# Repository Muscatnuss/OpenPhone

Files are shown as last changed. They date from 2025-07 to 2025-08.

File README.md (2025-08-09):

# Open Phone

# ToDo
- [ ] Accessories
	- [ ] Flashlight
- [ ] Human Interface
	- [ ] Vibration
	- [ ] Speaker
	- [ ] Fingerprint Sensor
- [ ] Connectivity
	- [x] Data - USB-C
		- [x] (SBUS Data)
	- [ ] (LORA communication)
		- meshtastic
	- [x] Cellular
- [ ] Sensors
	- [x] IMU
	- [x] Magnetometer
	- [ ] Fingerprint
- [ ] Video
	- [ ] Display
	- [ ] Camera
	- [ ] HDMI
- [ ] Audio
	- [ ] cellular audio $\to$ USB
	- [ ] CM5 audio IO
- [ ] Power
	- [ ] Load Switch 
		- [x] Modem
		- [ ] Camera
		- [ ] Mic
	- [x] USB-C Power delivery
	- [x] Power usage monitoring
		- [x] Current Monitor
		- [x] Voltage Monitor
# Hardware
- Back of PCB should face the screen
	- only very flat components on back
- PCB cutout for battery
    - Battery and PCB are on the same height to save space 

## Thermal management
- all significant heat producers face back
- Battery and screen keep a distance to hot spots

## Controller
Raspberry pi compute Module
https://www.raspberrypi.com/documentation/computers/compute-module.html#compute-module-5
https://datasheets.raspberrypi.com/cm5/cm5-datasheet.pdf
$\to$ 5V supply
$\to$ [Board connector](https://www.mouser.de/ProductDetail/Amphenol-FCI/10164227-1001A1RLF?qs=MyNHzdoqoQIc%2Fqhi8q%2FTOw%3D%3D)
Normalbetrieb unter Last $\to$ ~500mA

## Speicher
### SD Karte
- over SPI

## Screen
IPhone Xr 460ppi  ~6 Zoll

| | size  | maße | resolution  | price | Flex | Händler |
| --- | ----- | --- | --- | ----- | ---- | --- |
| [FLEX](https://www.alibaba.com/product-detail/Super-Thin-6-67-inch-1080_1601047701892.html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) | 6,67" | 165,16mm x 71,532mm x 0,33mm | 1080 x 2160 | 95€ | ja | Alibaba |
| [6" Flex](https://www.alibaba.com/product-detail/360-Degree-Bendable-6-Inch-Flexible_1600485553315.html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) | 6" | 68.04 x 136,08mm | 1080 x 2160 | 95€ | ja | Alibaba |

## Connectivity

- WLan $\to$ schon da
- Bluetooth $\to$  schon da
- micro HDMI $\to$ just add connector
- Ethernet?
- Phone network
- NFC
- USB-C
	- device mode
	- host mode
		- USB-Sticks und so
- Headphone-jack

### 3G 4G 5G

| Link | Price | | | Manual |
| --- | ----- | --- | --- | --- |
| https://mc-technologies.com/produkt/162368/ | 70€ | | | |
| SIM7600G-H | ~40€  | mit GPS | Dev-Board müsste man nachbauen, sollte aber nicht so wild sein | https://fcc.report/FCC-ID/2AJYU-8PYA007/4857209.pdf |
| | | | | |

[NAU8810](https://octopart.com/de/datasheet/nau8810yg-nuvoton-29622521 ) $\to$ Audio Codec
[Microphone](https://octopart.com/de/ics-40618-invensense-71346755)

## Powersupply
$\to$ 5V Akku Ladeelektronik
[load switch](https://www.ti.com/lit/ds/symlink/tps22917.pdf?ts=1749349462384)

### Battery Controller
Charge and boost controller, Power Path Management
availlable JLC
[BQ25895](https://www.ti.com/lit/ds/symlink/bq25895.pdf) ~3€

### Battery

| Kapazität | Maße | Preis | Händler |
| --- | --- | ----- | --- |
| [5000mAh](https://www.alibaba.com/product-detail/Lithium-Polymer-ultra-Thin-Lipo-3_1868172466.html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) | 6 x 50 x 82 | 3,80€ | Alibaba |
| [5500mAh](https://www.alibaba.com/product-detail/3-7-V-407595-5500mah-Factory_62168748778.html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) | 4 x 75 x 95mm  | 6,39€ | Alibaba |
| [10000mAh](https://www.alibaba.com/product-detail/8065113-3-7V-Lipo-Battery-10000mah_62109571526.html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) | 8 x 65 x 113mm | 8,50€ | Alibaba |

## Sensors

- [[Inertial Measurement Unit|IMU]]
- 3D [[Magnetometer]]
- Fingerprint sensor
	- https://biometrics.mainguet.org/types/fingerprint/product/FPC/FPC_1020_flyer.pdf
		- SPI
- Camera

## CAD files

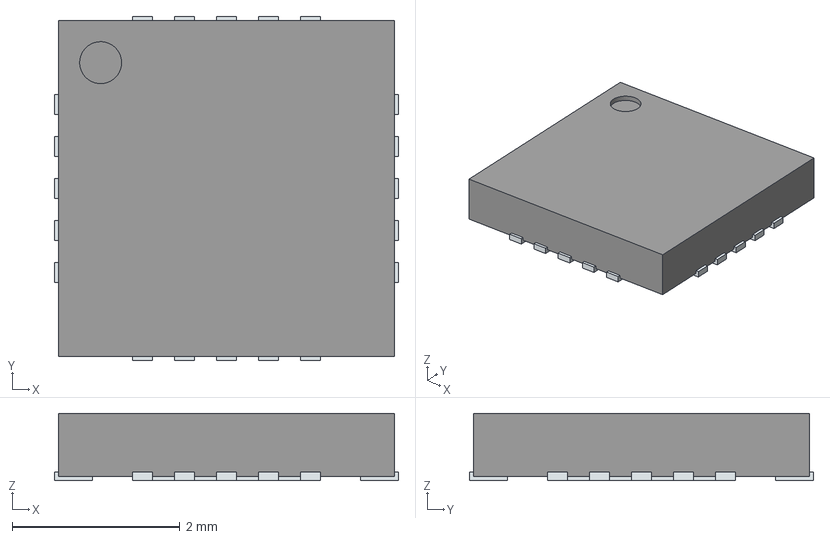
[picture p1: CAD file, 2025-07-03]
resources/LIB_NAU8810YG/NAU8810YG/3D/NAU8810YG.stp
4.10 x 4.10 x 0.8 mm
ThermalPin
PinsArrayLR
PinsArrayTB

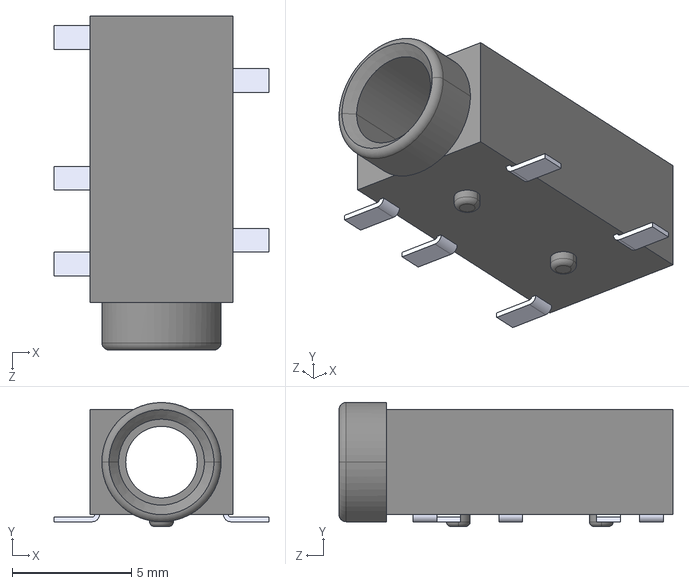
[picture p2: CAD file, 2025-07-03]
resources/10038075_A1PLF/10038075-A1PLF.step
9.00 x 5.20 x 14.0 mm

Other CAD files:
cad/SIM7600G-H.ipt
cad/mechanical/battery.ipt
cad/mechanical/battery_5000.ipt

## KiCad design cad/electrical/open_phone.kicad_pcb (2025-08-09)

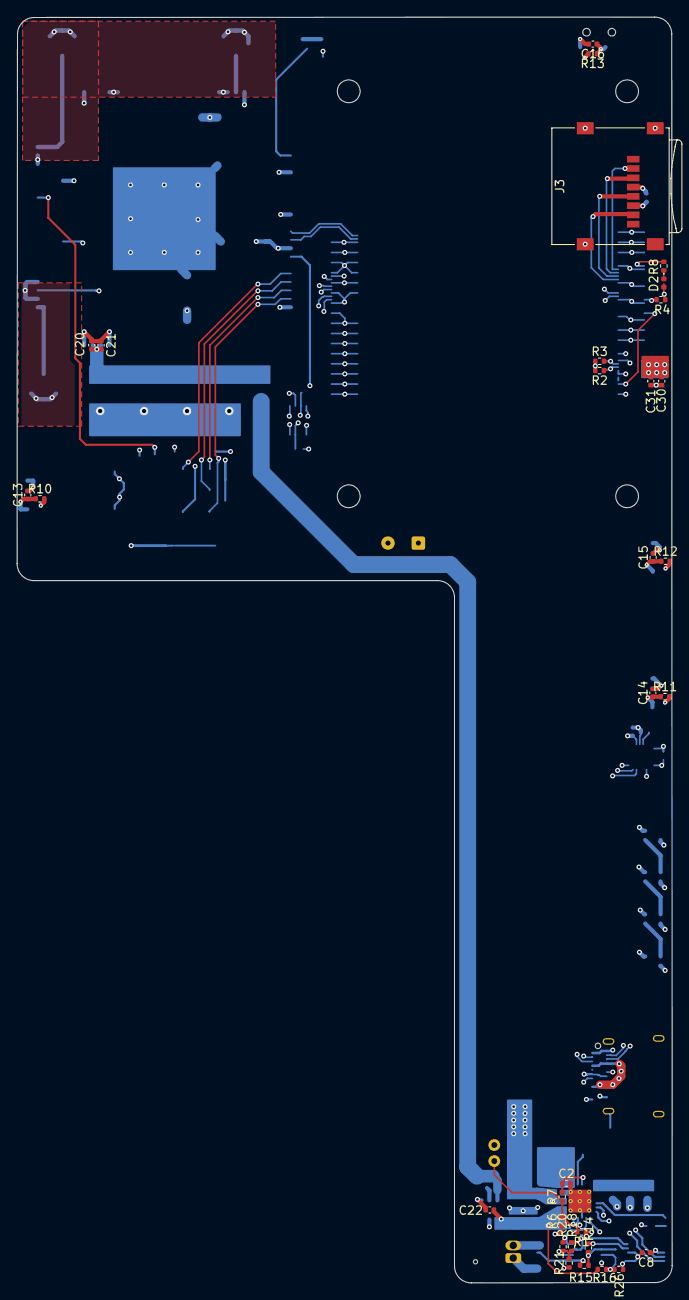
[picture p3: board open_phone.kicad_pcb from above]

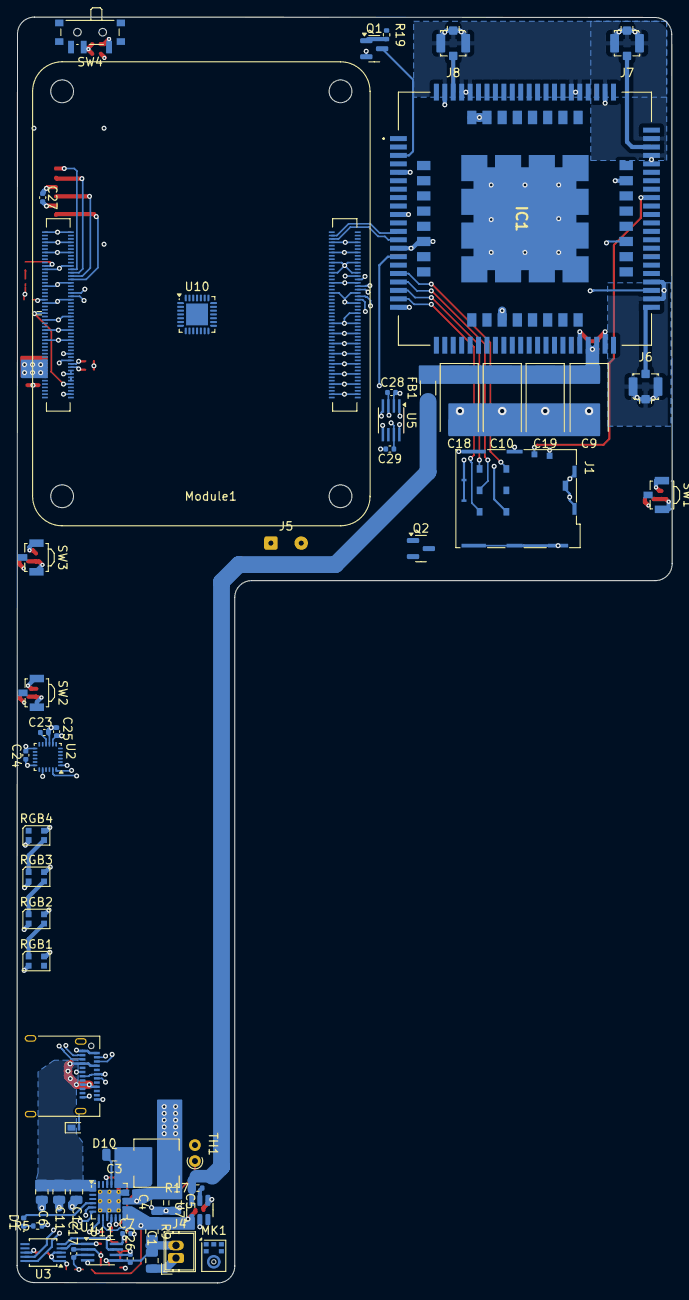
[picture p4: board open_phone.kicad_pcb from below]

Board: 6 copper layers, 77.6 x 150.0 mm, 87 parts (56 on the bottom side), 70 nets.

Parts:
C1, C3, C4, C5, C6, C11, C12: C; C_0805_2012Metric
C2, C7, C8, C13, C14, C15, C16, C17, C26, C27, C28, C29: C; C_0402_1005Metric
C9, C10, C18, C19: 100µF; CP_EIA-7343-31_Kemet-D
C20, C21, C22, C23, C24, C25, C30, C31: 100nF; C_0402_1005Metric
D1, D2: LED; LED_0402_1005Metric
D10: 12V; Nexperia_DSN1608-2_1.6x0.8mm
FB1: FerriteBead; L_1206_3216Metric
IC1: SIM7600G-H; SIM7600GH
J1: JAE_SIM_Card_SF72S006
J2: USB_C_Receptacle; USB_C_Receptacle_Amphenol_12401610E4-2A
J3: Micro_SD_Card; microSD_HC_Wuerth_693072010801
J4: Battery; Wuerth_WR-WTB_64800211622_1x02_P1.50mm_Vertical
J5: VIB; SolderWire-0.1sqmm_1x02_P3.6mm_D0.4mm_OD1mm
J6, J7, J8: conn_coax; U.FL_Molex_MCRF_73412-0110_Vertical
L1: L; L_Changjiang_FXL0518
MK1: ICS-43434; InvenSense_ICS-43434-6_3.5x2.65mm
Module1: ComputeModule5-CM5; Raspberry-Pi-5-Compute-Module
Q1, Q2: BC848; SOT-23
R1, R2, R3, R4, R5, R6, R7, R8, R10, R11, R12, R13, R14, R15, R16, R17, R18, R19, R20, R21, R26: R; R_0402_1005Metric
R9: R; R_0805_2012Metric
RGB1, RGB2, RGB3, RGB4: WS2812B-2020; LED_WS2812B-2020_PLCC4_2.0x2.0mm
SW1, SW2, SW3: SW_Push; SW_SPST_B3U-3100P
SW4: SW_SPST; SW_SPDT_PCM12
TH1: Thermistor_NTC; R_Axial_DIN0204_L3.6mm_D1.6mm_P1.90mm_Vertical
U1: BQ25895RTW; Texas_RTW_WQFN-24-1EP_4x4mm_P0.5mm_EP2.7x2.7mm_ThermalVias
U2: MPU-9250; InvenSense_QFN-24_3x3mm_P0.4mm
U3: ADS1013IDGS; TSSOP-10_3x3mm_P0.5mm
U5: TXS0102DCT; SSOP-8_2.95x2.8mm_P0.65mm
U7: TPS22917DBV; SOT-23-6
U10: ES8388; QFN-28-1EP_4x4mm_P0.45mm_EP2.6x2.6mm
U11: OPA2197xDGK; SSOP-8_2.95x2.8mm_P0.65mm

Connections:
+1V8: Module1.88 (+1.8v_(Output)), Module1.90 (+1.8v_(Output))
+1V8_CELL: C29.1, IC1.15 (VDD_1V8), U5.7 (VCCB)
+3.3V: C24.1, C25.1, C27.1, C28.2, D2.2 (A), J3.4 (VDD), J5.1, Module1.78 (GPIO_VREF(1.8v/3.3v_Input)), Module1.84 (+3.3v_(Output)), Module1.86 (+3.3v_(Output)), R2.2, R3.2, R4.2, RGB1.4 (VDD), RGB2.4 (VDD), RGB3.4 (VDD), RGB4.4 (VDD), U2.8 (VDDIO), U2.13 (VDD), U5.3 (VCCA)
+3V3: R10.2, R11.2, R12.2, R13.2, U2.1 (RESV_VDDIO)
+5V: C4.1, C5.1, C7.1, C8.1, C30.1, C31.1, L1.2, Module1.77 (+5v_(Input)), Module1.79 (+5v_(Input)), Module1.81 (+5v_(Input)), Module1.83 (+5v_(Input)), Module1.85 (+5v_(Input)), Module1.87 (+5v_(Input)), R5.1, R20.2, U1.15 (SYS), U1.16 (SYS), U3.8 (VDD), U11.8 (V+)
/cellular/MODEM_DBG_RX: IC1.106 (DBG_RXD), U5.8 (B1)
/cellular/MODEM_DBG_TX: IC1.42 (DBG_TXD), U5.1 (B2)
/cellular/MODEM_POWER: FB1.1, R17.1, U7.6 (VOUT)
/cellular/SW_MODEM: Module1.39 (GPIO8), U7.3 (ON)
/cellular/USB2_N: IC1.12 (USB_DN), Module1.103 (USB2_N)
/cellular/USB2_P: IC1.13 (USB_DP), Module1.105 (USB2_P)
/connectors/CC1: J2.A5 (CC1), Module1.94 (CC1)
/connectors/CC2: J2.B5 (CC2), Module1.96 (CC2)
/connectors/USB3-0-DN: J2.A7 (D-), J2.B7 (D-), Module1.134 (USB3-0-D_P)
/connectors/USB3-0-DP: J2.A6 (D+), J2.B6 (D+), Module1.136 (USB3-0-D_N)
/connectors/USB3-0-RX_N: J2.B10 (RX1-), Module1.130 (USB3-0-RX_P)
/connectors/USB3-0-RX_P: J2.B11 (RX1+), Module1.128 (USB3-0-RX_N)
/connectors/USB3-0-TX_N: J2.A3 (TX1-), Module1.142 (USB3-0-TX_P)
/connectors/USB3-0-TX_P: J2.A2 (TX1+), Module1.140 (USB3-0-TX_N)
/controller/CS: J3.2 (DAT3/CD), Module1.24 (GPIO26)
/controller/GPIO25: Module1.41 (GPIO25), R4.1, U1.7 (INT)
/controller/MISO: J3.3 (CMD), Module1.26 (GPIO19)
/controller/MOSI: J3.7 (DAT0), Module1.30 (GPIO6)
/controller/SCL0: Module1.80 (SCL0), R3.1, U1.5 (SCL), U2.23 (SCL/SCLK), U3.10 (SCL)
/controller/SCLK: J3.5 (CLK), Module1.28 (GPIO13)
/controller/SDA0: Module1.82 (SDA0), R2.1, U1.6 (SDA), U2.24 (SDA/MOSI), U3.9 (SDA)
/controller/UART0_RX: Module1.40 (GPIO9), U5.5 (A1)
/controller/UART0_TX: Module1.38 (GPIO11), U5.4 (A2)
BTTN_VOL_+: C14.1, R11.1, SW2.2
BTTN_VOL_-: C15.1, R12.1, SW3.2
BTTN_unlock: C13.1, Module1.49 (GPIO18), Module1.92 (PWR_BUT), R10.1, SW1.2
GND: C1.2, C2.2, C4.2, C5.2, C6.1, C7.2, C8.2, C9.2, C10.2, C11.1, C12.1, C13.2, C14.2, C15.2, C16.2, C18.2, C19.2, C20.2, C21.2, C23.2, C24.2, C25.2, C27.2, C28.1, C29.2, C30.2, C31.2, D10.2 (A), IC1.1 (GND_1), IC1.2 (GND_2), IC1.5 (GND_3), IC1.10 (GND_4), IC1.14 (GND_5), IC1.37 (GND_6), IC1.40 (GND_7), IC1.41 (GND_8), IC1.43 (GND_9), IC1.57 (GND_10), IC1.58 (GND_11), IC1.60 (GND_12), IC1.61 (GND_13), IC1.64 (GND_14), IC1.65 (GND_15), IC1.77 (GND_16), IC1.78 (GND_17), IC1.80 (GND_18), IC1.81 (GND_19), IC1.93 (GND_20), IC1.98 (GND_21), IC1.110 (GND_22), IC1.118 (GND_23), IC1.119 (GPIO_19), IC1.120 (GND_24), IC1.121 (GND_25), IC1.122 (GND_26), IC1.123 (GND_27), IC1.124 (GND_28), IC1.125 (GND_29), IC1.126 (GND_30), IC1.127 (GND_31), IC1.128 (GND_32), IC1.129 (GND_33), IC1.130 (GND_34), IC1.131 (GND_35), IC1.132 (GND_36), IC1.133 (GND_37), IC1.134 (GND_38), IC1.135 (GND_39), J1.C5 (GND), J1.DSW, J1.SH, J2.A1 (GND), J2.A12 (GND), J2.B1 (GND), J2.B12 (GND), J2.S1 (SHIELD), J3.6 (VSS), J3.9 (SHIELD), J4.1, J6.2 (Ext), J7.2 (Ext), J8.2 (Ext), Module1.1 (GND), Module1.2 (GND), Module1.7 (GND), Module1.8 (GND), Module1.13 (GND), Module1.14 (GND), Module1.22 (GND), Module1.23 (GND), Module1.32 (GND), Module1.33 (GND), Module1.42 (GND), Module1.43 (GND), Module1.52 (GND), Module1.53 (GND), Module1.59 (GND), Module1.60 (GND), Module1.65 (GND), Module1.66 (GND), Module1.74 (GND), Module1.98 (GND), Module1.107 (GND), Module1.108 (GND), Module1.113 (GND), Module1.114 (GND), Module1.119 (GND), Module1.120 (GND), Module1.125 (GND), Module1.126 (GND), Module1.131 (GND), Module1.132 (GND), Module1.137 (GND), Module1.138 (GND), Module1.144 (GND), Module1.150 (GND), Module1.155 (GND), Module1.156 (GND), Module1.161 (GND), Module1.162 (GND), Module1.167 (GND), Module1.168 (GND), Module1.173 (GND), Module1.174 (GND), Module1.179 (GND), Module1.180 (GND), Module1.185 (GND), Module1.186 (GND), Module1.191 (GND), Module1.192 (GND), Module1.197 (GND), Module1.198 (GND), Q1.2 (E), Q2.2 (E), R1.1, R6.1, R21.1, R26.2, RGB1.2 (VSS), RGB2.2 (VSS), RGB3.2 (VSS), RGB4.2 (VSS), SW1.1, SW2.1, SW3.1, SW4.1 (A), TH1.2, U1.9 (~CE), U1.17 (PGND), U1.18 (PGND), U1.25 (PGND), U2.9 (AD0/MISO), U2.18 (GND), U2.20 (RESV_GND), U3.1 (ADDR), U3.3 (GND), U5.2 (GND), U7.2 (GND), U11.4 (V-)
LED_nACT: Module1.21 (LED_nACT), R8.1
unnamed: C3.1, L1.1, U1.19 (SW), U1.20 (SW)
unnamed: D1.2 (A), U1.4 (STAT)
unnamed: D1.1 (K), R5.2
unnamed: D2.1 (K), R8.2
unnamed: IC1.59 (AUX_ANT), J7.1 (In)
unnamed: IC1.79 (GNSS_ANT), J8.1 (In)
unnamed: IC1.82 (MAIN_ANT), J6.1 (In)
unnamed: IC1.3 (PWRKEY), Q1.3 (C)
unnamed: IC1.19 (USIM_CLK), J1.C3 (CLK)
unnamed: IC1.17 (USIM_DATA), J1.C7 (I/O)
unnamed: IC1.53 (USIM_DET~), J1.CSW
unnamed: IC1.18 (USIM_RST), J1.C2 (RST)
unnamed: IC1.20 (USIM_VDD), J1.C1 (VCC)
unnamed: C9.1, C10.1, C18.1, C19.1, C20.1, C21.1, FB1.2, IC1.38 (VBAT_1), IC1.39 (VBAT_2)
unnamed: C1.1, C26.2, J4.2, R9.2, R15.2, U11.5 (+)
unnamed: J5.2, Q2.3 (C)
unnamed: Module1.45 (GPIO24), Module1.91 (BT_nDisable)
unnamed: Module1.47 (GPIO23), Module1.89 (WiFi_nDisable)
unnamed: Q1.1 (B), R19.1
unnamed: RGB1.1 (DOUT), RGB2.3 (DIN)
unnamed: RGB2.1 (DOUT), RGB3.3 (DIN)
unnamed: RGB3.1 (DOUT), RGB4.3 (DIN)
unnamed: C3.2, U1.21 (BTST)
unnamed: R1.2, U1.10 (ILIM)
unnamed: C2.1, R7.2, U1.22 (REGN)
unnamed: R6.2, R7.1, TH1.1, U1.11 (TS)
unnamed: C23.1, U2.10 (REGOUT)
unnamed: R14.1, U3.4 (AIN0), U11.1
unnamed: R18.2, U3.5 (AIN1), U11.7
unnamed: C22.2, U7.4 (CT)
unnamed: R17.2, U7.5 (QOD)
unnamed: C17.1, R16.1, R26.1, U11.3 (+)
unnamed: C17.2, R14.2, R15.1, U11.2 (-)
unnamed: C26.1, R18.1, R20.1, R21.2, U11.6 (-)
SW_silent: C16.1, R13.1, SW4.2 (B)
VBUS_DP: C6.2, C11.2, C12.2, D10.1 (K), J2.A4 (VBUS), J2.A9 (VBUS), J2.B4 (VBUS), J2.B9 (VBUS), U1.1 (VBUS)
V_BAT: C22.1, R9.1, R16.2, U1.8 (OTG), U1.13 (BAT), U1.14 (BAT), U7.1 (VIN)

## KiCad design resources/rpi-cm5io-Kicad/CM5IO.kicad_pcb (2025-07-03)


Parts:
C9, C18: 100n; C_0402_1005Metric; Part Description 0.1uF 10% 16V Ceramic Capacitor X7R 040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
H1, H2, H3, H4, H5, H6, H7, H8: MountingHole; MountingHole_2.7mm_M2.5_DIN965; Part Description M2.5 mounting hole; not fitted
J11: USB_C_Receptacle_USB2.0; USB_C_Receptacle_GCT_USB4105-xx-A_16P_TopMnt_Horizontal; Part Description USBC USB2 data and power connector
R9: 2.2K 1%; R_0402_1005Metric; Part Description Resistor 2.2K M1005 1% 63mW

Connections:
/+5v: C9.1, C18.1, J11.A4 (VBUS), J11.A9 (VBUS), J11.B4 (VBUS), J11.B9 (VBUS), R9.1; also elsewhere on the board
/CC1: J11.A5 (CC1); also elsewhere on the board
/CC2: J11.B5 (CC2); also elsewhere on the board
/USB2_N: J11.A7 (D-), J11.B7 (D-); also elsewhere on the board
/USB2_P: J11.A6 (D+), J11.B6 (D+); also elsewhere on the board
GND: C9.2, C18.2, J11.A1 (GND), J11.A12 (GND), J11.B1 (GND), J11.B12 (GND), J11.S1 (SHIELD), R9.2; also elsewhere on the board

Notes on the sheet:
Connectors ------- Ethernet SDCARD 40way RPI Jumpers Fan Battery
Connectors ------ M2 MKey
Discharge Resistor Needed by some Type C PSUs
TypeC Power connector
Connectors ------- HDMI 0 HDMI 1 CSI/DSI 0 CSI/DSI 1

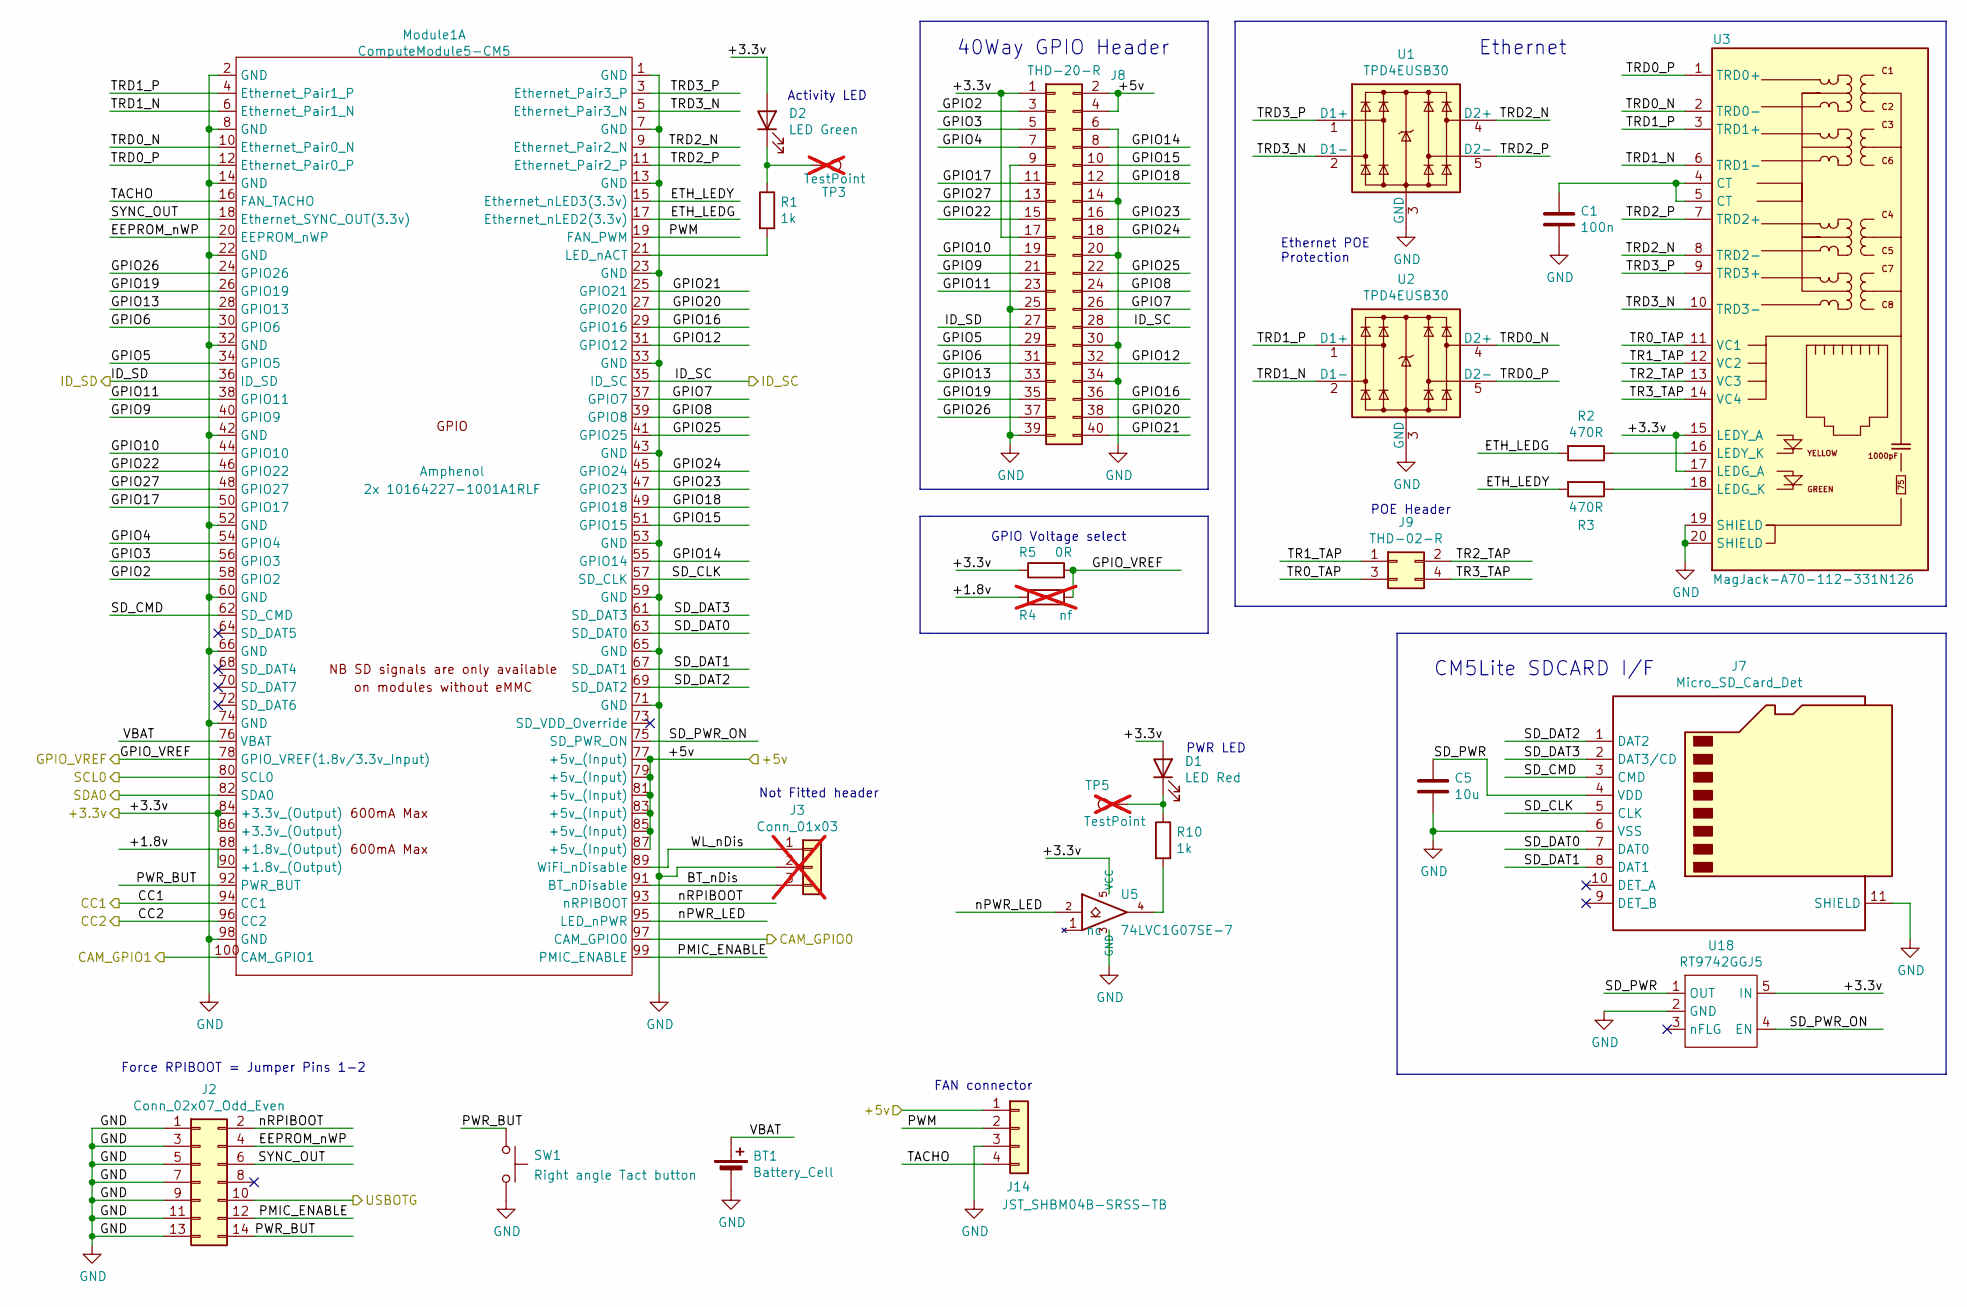
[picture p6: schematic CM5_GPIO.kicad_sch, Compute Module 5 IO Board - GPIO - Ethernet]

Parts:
BT1: Battery_Cell; BatteryHolder_Keystone_3034_1x20mm; Part Description Battery Retainer Coin, 20.0mm 1 Cell SM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
C1: 100n; C_0402_1005Metric; Part Description 0.1uF 10% 16V Ceramic Capacitor X7R 040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
C5: 10u; C_0805_2012Metric; Part Description 10uF 10% 10V Ceramic Capacitor X7R 0805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
D1: LED Red; LED_0603_1608Metric; Part Description Red 620nm LED Indication - Discrete 2.2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
D2: LED Green; LED_0603_1608Metric; Part Description Green 572nm LED Indication - Discrete 2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
J2: Conn_02x07_Odd_Even; PinHeader_2x07_P2.54mm_Vertical; Part Description PinHeader_2x07_P2.54mm_Vertical
J3: Conn_01x03; PinHeader_1x03_P2.54mm_Vertical; Part Description 3pin 0.1" connector; not fitted
J7: Micro_SD_Card_Det; SDCARD_MOLEX_503398-1892; Part Description 9 (8 + 1) Position Card Connector micro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
J8: THD-20-R; PinHeader_2x20_P2.54mm_Vertical; Part Description PinHeader_2x20_P2.54mm_Vertical
J9: THD-02-R; PinHeader_2x02_P2.54mm_Vertical; Part Description PinHeader_2x02_P2.54mm_Vertical
J14: JST_SHBM04B-SRSS-TB; JST_SH_BM04B-SRSS-TB_1x04-1MP_P1.00mm_Vertical; Part Description 4 pin vertical 1mm pitch connector
Module1: ComputeModule5-CM5; Raspberry-Pi-5-Compute-Module; Part Description 100 Position Connector Receptacle, Cent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
R1, R10: 1k; R_0402_1005Metric; Part Description Resistor 1K M1005 1% 63mW
R2, R3: 470R; R_0402_1005Metric; Part Description Resistor 470R M1005 1% 63mW
R4: nf; R_0805_2012Metric_Pad1.20x1.40mm_HandSolder; not fitted
R5: 0R; R_0805_2012Metric_Pad1.20x1.40mm_HandSolder; Part Description Resistor 0R M2012 5%
SW1: Right angle Tact button; SW_Tactile_SPST_Angled_PTS645Vx58-2LFS; Part Description Right angle through hole Tact switch
TP3, TP5: TestPoint; TestPoint_Pad_2.0x2.0mm; Part Description Test point; not fitted
U1, U2: TPD4EUSB30; USON-10_2.5x1.0mm_P0.5mm; Part Description Quad TVS diode for high speed signals (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
U3: MagJack-A70-112-331N126; TRJG0926HENL; Part Description Gigabit Ethernet Magjack
U5: 74LVC1G07SE-7; SOT-353_SC-70-5; Part Description Buffer, Non-Inverting 1 Element 1 Bit p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
U18: RT9742GGJ5; SOT-23-5; Part Description Power Switch/Driver 1:1 N-Channel 1A TS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

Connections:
/+3.3v: D1.2 (A), D2.2 (A), J8.1, J8.17, Module1.84 (+3.3v_(Output)), Module1.86 (+3.3v_(Output)), R5.1, U3.15 (LEDY_A), U3.17 (LEDG_A), U5.5 (VCC), U18.5 (IN); also elsewhere on the board
/+5v: J8.2, J8.4, J14.1, Module1.77 (+5v_(Input)), Module1.79 (+5v_(Input)), Module1.81 (+5v_(Input)), Module1.83 (+5v_(Input)), Module1.85 (+5v_(Input)), Module1.87 (+5v_(Input)); also elsewhere on the board
/CC1: Module1.94 (CC1); also elsewhere on the board
/CC2: Module1.96 (CC2); also elsewhere on the board
/CM5_GPIO ( Ethernet, GPIO, SDCARD)/+1.8v: Module1.88 (+1.8v_(Output)), Module1.90 (+1.8v_(Output)), R4.1
/CM5_GPIO ( Ethernet, GPIO, SDCARD)/BT_nDis: J3.3, Module1.91 (BT_nDisable)
/CM5_GPIO ( Ethernet, GPIO, SDCARD)/CAM_GPIO0: Module1.97 (CAM_GPIO0); also elsewhere on the board
/CM5_GPIO ( Ethernet, GPIO, SDCARD)/CAM_GPIO1: Module1.100 (CAM_GPIO1); also elsewhere on the board
/CM5_GPIO ( Ethernet, GPIO, SDCARD)/EEPROM_nWP: J2.4, Module1.20 (EEPROM_nWP)
/CM5_GPIO ( Ethernet, GPIO, SDCARD)/ETH_LEDG: Module1.17 (Ethernet_nLED2(3.3v)), R2.2
/CM5_GPIO ( Ethernet, GPIO, SDCARD)/ETH_LEDY: Module1.15 (Ethernet_nLED3(3.3v)), R3.2
/CM5_GPIO ( Ethernet, GPIO, SDCARD)/GPIO2: J8.3, Module1.58 (GPIO2)
/CM5_GPIO ( Ethernet, GPIO, SDCARD)/GPIO3: J8.5, Module1.56 (GPIO3)
/CM5_GPIO ( Ethernet, GPIO, SDCARD)/GPIO4: J8.7, Module1.54 (GPIO4)
/CM5_GPIO ( Ethernet, GPIO, SDCARD)/GPIO5: J8.29, Module1.34 (GPIO5)
/CM5_GPIO ( Ethernet, GPIO, SDCARD)/GPIO6: J8.31, Module1.30 (GPIO6)
/CM5_GPIO ( Ethernet, GPIO, SDCARD)/GPIO7: J8.26, Module1.37 (GPIO7)
/CM5_GPIO ( Ethernet, GPIO, SDCARD)/GPIO8: J8.24, Module1.39 (GPIO8)
/CM5_GPIO ( Ethernet, GPIO, SDCARD)/GPIO9: J8.21, Module1.40 (GPIO9)
/CM5_GPIO ( Ethernet, GPIO, SDCARD)/GPIO10: J8.19, Module1.44 (GPIO10)
/CM5_GPIO ( Ethernet, GPIO, SDCARD)/GPIO11: J8.23, Module1.38 (GPIO11)
/CM5_GPIO ( Ethernet, GPIO, SDCARD)/GPIO12: J8.32, Module1.31 (GPIO12)
/CM5_GPIO ( Ethernet, GPIO, SDCARD)/GPIO13: J8.33, Module1.28 (GPIO13)
/CM5_GPIO ( Ethernet, GPIO, SDCARD)/GPIO14: J8.8, Module1.55 (GPIO14)
/CM5_GPIO ( Ethernet, GPIO, SDCARD)/GPIO15: J8.10, Module1.51 (GPIO15)
/CM5_GPIO ( Ethernet, GPIO, SDCARD)/GPIO16: J8.36, Module1.29 (GPIO16)
/CM5_GPIO ( Ethernet, GPIO, SDCARD)/GPIO17: J8.11, Module1.50 (GPIO17)
/CM5_GPIO ( Ethernet, GPIO, SDCARD)/GPIO18: J8.12, Module1.49 (GPIO18)
/CM5_GPIO ( Ethernet, GPIO, SDCARD)/GPIO19: J8.35, Module1.26 (GPIO19)
/CM5_GPIO ( Ethernet, GPIO, SDCARD)/GPIO20: J8.38, Module1.27 (GPIO20)
/CM5_GPIO ( Ethernet, GPIO, SDCARD)/GPIO21: J8.40, Module1.25 (GPIO21)
/CM5_GPIO ( Ethernet, GPIO, SDCARD)/GPIO22: J8.15, Module1.46 (GPIO22)
/CM5_GPIO ( Ethernet, GPIO, SDCARD)/GPIO23: J8.16, Module1.47 (GPIO23)
/CM5_GPIO ( Ethernet, GPIO, SDCARD)/GPIO24: J8.18, Module1.45 (GPIO24)
/CM5_GPIO ( Ethernet, GPIO, SDCARD)/GPIO25: J8.22, Module1.41 (GPIO25)
/CM5_GPIO ( Ethernet, GPIO, SDCARD)/GPIO26: J8.37, Module1.24 (GPIO26)
/CM5_GPIO ( Ethernet, GPIO, SDCARD)/GPIO27: J8.13, Module1.48 (GPIO27)
/CM5_GPIO ( Ethernet, GPIO, SDCARD)/GPIO_VREF: Module1.78 (GPIO_VREF(1.8v/3.3v_Input)), R4.2, R5.2; also elsewhere on the board
/CM5_GPIO ( Ethernet, GPIO, SDCARD)/ID_SC: J8.28, Module1.35 (ID_SC); also elsewhere on the board
/CM5_GPIO ( Ethernet, GPIO, SDCARD)/ID_SD: J8.27, Module1.36 (ID_SD); also elsewhere on the board
/CM5_GPIO ( Ethernet, GPIO, SDCARD)/PMIC_ENABLE: J2.12, Module1.99 (PMIC_ENABLE)
/CM5_GPIO ( Ethernet, GPIO, SDCARD)/PWM: J14.2, Module1.19 (FAN_PWM)
/CM5_GPIO ( Ethernet, GPIO, SDCARD)/PWR_BUT: J2.14, Module1.92 (PWR_BUT), SW1.1
/CM5_GPIO ( Ethernet, GPIO, SDCARD)/SD_CLK: J7.5 (CLK), Module1.57 (SD_CLK)
/CM5_GPIO ( Ethernet, GPIO, SDCARD)/SD_CMD: J7.3 (CMD), Module1.62 (SD_CMD)
/CM5_GPIO ( Ethernet, GPIO, SDCARD)/SD_DAT0: J7.7 (DAT0), Module1.63 (SD_DAT0)
/CM5_GPIO ( Ethernet, GPIO, SDCARD)/SD_DAT1: J7.8 (DAT1), Module1.67 (SD_DAT1)
/CM5_GPIO ( Ethernet, GPIO, SDCARD)/SD_DAT2: J7.1 (DAT2), Module1.69 (SD_DAT2)
/CM5_GPIO ( Ethernet, GPIO, SDCARD)/SD_DAT3: J7.2 (DAT3/CD), Module1.61 (SD_DAT3)
/CM5_GPIO ( Ethernet, GPIO, SDCARD)/SD_PWR: C5.1, J7.4 (VDD), U18.1 (OUT)
/CM5_GPIO ( Ethernet, GPIO, SDCARD)/SD_PWR_ON: Module1.75 (SD_PWR_ON), U18.4 (EN)
/CM5_GPIO ( Ethernet, GPIO, SDCARD)/SYNC_OUT: J2.6, Module1.18 (Ethernet_SYNC_OUT(1.8v))
/CM5_GPIO ( Ethernet, GPIO, SDCARD)/TACHO: J14.4, Module1.16 (FAN_TACHO)
/CM5_GPIO ( Ethernet, GPIO, SDCARD)/TR0_TAP: J9.3, U3.11 (VC1)
/CM5_GPIO ( Ethernet, GPIO, SDCARD)/TR1_TAP: J9.1, U3.12 (VC2)
/CM5_GPIO ( Ethernet, GPIO, SDCARD)/TR2_TAP: J9.2, U3.13 (VC3)
/CM5_GPIO ( Ethernet, GPIO, SDCARD)/TR3_TAP: J9.4, U3.14 (VC4)
/CM5_GPIO ( Ethernet, GPIO, SDCARD)/TRD0_N: Module1.10 (Ethernet_Pair0_N), U2.4 (D2+), U2.7, U3.2 (TRD0-)
/CM5_GPIO ( Ethernet, GPIO, SDCARD)/TRD0_P: Module1.12 (Ethernet_Pair0_P), U2.5 (D2-), U2.6, U3.1 (TRD0+)
/CM5_GPIO ( Ethernet, GPIO, SDCARD)/TRD1_N: Module1.6 (Ethernet_Pair1_N), U2.2 (D1-), U2.9, U3.6 (TRD1-)
/CM5_GPIO ( Ethernet, GPIO, SDCARD)/TRD1_P: Module1.4 (Ethernet_Pair1_P), U2.1 (D1+), U2.10, U3.3 (TRD1+)
/CM5_GPIO ( Ethernet, GPIO, SDCARD)/TRD2_N: Module1.9 (Ethernet_Pair2_N), U1.4 (D2+), U1.7, U3.8 (TRD2-)
/CM5_GPIO ( Ethernet, GPIO, SDCARD)/TRD2_P: Module1.11 (Ethernet_Pair2_P), U1.5 (D2-), U1.6, U3.7 (TRD2+)
/CM5_GPIO ( Ethernet, GPIO, SDCARD)/TRD3_N: Module1.5 (Ethernet_Pair3_N), U1.2 (D1-), U1.9, U3.10 (TRD3-)
/CM5_GPIO ( Ethernet, GPIO, SDCARD)/TRD3_P: Module1.3 (Ethernet_Pair3_P), U1.1 (D1+), U1.10, U3.9 (TRD3+)
/CM5_GPIO ( Ethernet, GPIO, SDCARD)/USBOTG: J2.10; also elsewhere on the board
/CM5_GPIO ( Ethernet, GPIO, SDCARD)/VBAT: BT1.1 (+), Module1.76 (VBAT)
/CM5_GPIO ( Ethernet, GPIO, SDCARD)/WL_nDis: J3.1, Module1.89 (WiFi_nDisable)
/CM5_GPIO ( Ethernet, GPIO, SDCARD)/nPWR_LED: Module1.95 (LED_nPWR), U5.2
/CM5_GPIO ( Ethernet, GPIO, SDCARD)/nRPIBOOT: J2.2, Module1.93 (nRPIBOOT)
/CM5_HighSpeed/SCL0: Module1.80 (SCL0); also elsewhere on the board
/CM5_HighSpeed/SDA0: Module1.82 (SDA0); also elsewhere on the board
GND: BT1.2 (-), C1.2, C5.2, J2.1, J2.3, J2.5, J2.7, J2.9, J2.11, J2.13, J3.2, J7.6 (VSS), J7.11 (SHIELD), J8.6, J8.9, J8.14, J8.20, J8.25, J8.30, J8.34, J8.39, J14.3, Module1.1 (GND), Module1.2 (GND), Module1.7 (GND), Module1.8 (GND), Module1.13 (GND), Module1.14 (GND), Module1.22 (GND), Module1.23 (GND), Module1.32 (GND), Module1.33 (GND), Module1.42 (GND), Module1.43 (GND), Module1.52 (GND), Module1.53 (GND), Module1.59 (GND), Module1.60 (GND), Module1.65 (GND), Module1.66 (GND), Module1.71 (GND), Module1.74 (GND), Module1.98 (GND), SW1.2, U1.3 (GND), U1.8 (GND), U2.3 (GND), U2.8 (GND), U3.19 (SHIELD), U3.20 (SHIELD), U5.3 (GND), U18.2 (GND); also elsewhere on the board
unnamed: C1.1, U3.4 (CT), U3.5 (CT)
unnamed: D1.1 (K), R10.1, TP5.1
unnamed: D2.1 (K), R1.1, TP3.1
unnamed: Module1.21 (LED_nACT), R1.2
unnamed: R10.2, U5.4
unnamed: R3.1, U3.18 (LEDG_K)
unnamed: R2.1, U3.16 (LEDY_K)

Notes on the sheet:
40Way GPIO Header
Activity LED
FAN connector
Ethernet POE Protection
GPIO Voltage select
Not Fitted header
POE Header
Force RPIBOOT = Jumper Pins 1-2
PWR LED
Ethernet
CM5Lite SDCARD I/F

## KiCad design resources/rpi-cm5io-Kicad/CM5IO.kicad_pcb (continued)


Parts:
C2, C7, C8: 10u; C_0805_2012Metric; Part Description 10uF 10% 10V Ceramic Capacitor X7R 0805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
C3: 100uF; CP_EIA-7343-31_Kemet-D; Part Description Capacitor, SP-Cap, 100u, 6.3V, 15mR ESR
C12, C13: 100n; C_0402_1005Metric; Part Description 0.1uF 10% 16V Ceramic Capacitor X7R 040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
J5, J16: Conn_01x22_Female; Hirose_FH12-22S-0.5SH_1x22-1MP_P0.50mm_Horizontal; Part Description 22 Position FFC, FPC Connector Contacts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
J6: THD-02-R; PinHeader_2x02_P2.54mm_Vertical; Part Description PinHeader_2x02_P2.54mm_Vertical
J10, J22: 690-019-298-412; EDAC 690-019-298-412; Part Description HDMI Connector, Right Angle, 19 Contact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
J12: USB3_A; MTCONN_UBAF30-D2011; Part Description Dual USB 3 connector
Module1: ComputeModule5-CM5; Raspberry-Pi-5-Compute-Module; Part Description 100 Position Connector Receptacle, Cent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
R6, R7, R8: 2.2K 1%; R_0402_1005Metric; Part Description Resistor 2.2K M1005 1% 63mW
R12: 15K 1%; R_0402_1005Metric; Part Description Resistor 15K M1005 1% 63mW
U6: AP22653W6; SOT-23-6; Part Description Power Switch/Driver 1:1 P-Channel 2.1A 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
U12: RT9742SNGV; TSOT-23_HandSoldering; Part Description Power Switch/Driver 1:1 N-Channel 500mA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

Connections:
/+3.3v: J5.22, J16.22, R8.1; also elsewhere on the board
/+5v: C2.1, C12.1, U6.1 (IN), U12.1 (IN); also elsewhere on the board
/CM5_GPIO ( Ethernet, GPIO, SDCARD)/CAM_GPIO0: J5.17; also elsewhere on the board
/CM5_GPIO ( Ethernet, GPIO, SDCARD)/CAM_GPIO1: J5.18; also elsewhere on the board
/CM5_GPIO ( Ethernet, GPIO, SDCARD)/GPIO_VREF: R6.1, R7.1; also elsewhere on the board
/CM5_GPIO ( Ethernet, GPIO, SDCARD)/ID_SC: J6.1; also elsewhere on the board
/CM5_GPIO ( Ethernet, GPIO, SDCARD)/ID_SD: J6.3; also elsewhere on the board
/CM5_GPIO ( Ethernet, GPIO, SDCARD)/USBOTG: Module1.101 (USB_OTG_ID); also elsewhere on the board
/CM5_HighSpeed/DPHY0_C_N: J5.8, Module1.127 (DPHY0_C_N)
/CM5_HighSpeed/DPHY0_C_P: J5.9, Module1.129 (DPHY0_C_P)
/CM5_HighSpeed/DPHY0_D0_N: J5.2, Module1.115 (DPHY0_D0_N)
/CM5_HighSpeed/DPHY0_D0_P: J5.3, Module1.117 (DPHY0_D0_P)
/CM5_HighSpeed/DPHY0_D1_N: J5.5, Module1.121 (DPHY0_D1_N)
/CM5_HighSpeed/DPHY0_D1_P: J5.6, Module1.123 (DPHY0_D1_P)
/CM5_HighSpeed/DPHY0_D2_N: J5.11, Module1.133 (DPHY0_D2_N)
/CM5_HighSpeed/DPHY0_D2_P: J5.12, Module1.135 (DPHY0_D2_P)
/CM5_HighSpeed/DPHY0_D3_N: J5.14, Module1.139 (DPHY0_D3_N)
/CM5_HighSpeed/DPHY0_D3_P: J5.15, Module1.141 (DPHY0_D3_P)
/CM5_HighSpeed/DPHY1_C_N: J16.8, Module1.187 (DPHY1_C_N)
/CM5_HighSpeed/DPHY1_C_P: J16.9, Module1.189 (DPHY1_C_P)
/CM5_HighSpeed/DPHY1_D0_N: J16.2, Module1.175 (DPHY1_D0_N)
/CM5_HighSpeed/DPHY1_D0_P: J16.3, Module1.177 (DPHY1_D0_P)
/CM5_HighSpeed/DPHY1_D1_N: J16.5, Module1.181 (DPHY1_D1_N)
/CM5_HighSpeed/DPHY1_D1_P: J16.6, Module1.183 (DPHY1_D1_P)
/CM5_HighSpeed/DPHY1_D2_N: J16.11, Module1.193 (DPHY1_D2_N)
/CM5_HighSpeed/DPHY1_D2_P: J16.12, Module1.195 (DPHY1_D2_P)
/CM5_HighSpeed/DPHY1_D3_N: J16.14, Module1.194 (DPHY1_D3_N)
/CM5_HighSpeed/DPHY1_D3_P: J16.15, Module1.196 (DPHY1_D3_P)
/CM5_HighSpeed/HDMI0_CEC: J22.13 (CEC), Module1.151 (HDMI0_CEC)
/CM5_HighSpeed/HDMI0_CK_N: J22.12 (CK-), Module1.190 (HDMI0_CLK_N)
/CM5_HighSpeed/HDMI0_CK_P: J22.10 (CK+), Module1.188 (HDMI0_CLK_P)
/CM5_HighSpeed/HDMI0_D0_N: J22.9 (D0-), Module1.184 (HDMI0_TX0_N)
/CM5_HighSpeed/HDMI0_D0_P: J22.7 (D0+), Module1.182 (HDMI0_TX0_P)
/CM5_HighSpeed/HDMI0_D1_N: J22.6 (D1-), Module1.178 (HDMI0_TX1_N)
/CM5_HighSpeed/HDMI0_D1_P: J22.4 (D1+), Module1.176 (HDMI0_TX1_P)
/CM5_HighSpeed/HDMI0_D2_N: J22.3 (D2-), Module1.172 (HDMI0_TX2_N)
/CM5_HighSpeed/HDMI0_D2_P: J22.1 (D2+), Module1.170 (HDMI0_TX2_P)
/CM5_HighSpeed/HDMI0_HOTPLUG: J22.19 (HPD/HEAC-), Module1.153 (HDMI0_HOTPLUG)
/CM5_HighSpeed/HDMI0_SCL: J22.15 (SCL), Module1.200 (HDMI0_SCL)
/CM5_HighSpeed/HDMI0_SDA: J22.16 (SDA), Module1.199 (HDMI0_SDA)
/CM5_HighSpeed/HDMI1_CEC: J10.13 (CEC), Module1.149 (HDMI1_CEC)
/CM5_HighSpeed/HDMI1_CK_N: J10.12 (CK-), Module1.166 (HDMI1_CLK_N)
/CM5_HighSpeed/HDMI1_CK_P: J10.10 (CK+), Module1.164 (HDMI1_CLK_P)
/CM5_HighSpeed/HDMI1_D0_N: J10.9 (D0-), Module1.160 (HDMI1_TX0_N)
/CM5_HighSpeed/HDMI1_D0_P: J10.7 (D0+), Module1.158 (HDMI1_TX0_P)
/CM5_HighSpeed/HDMI1_D1_N: J10.6 (D1-), Module1.154 (HDMI1_TX1_N)
/CM5_HighSpeed/HDMI1_D1_P: J10.4 (D1+), Module1.152 (HDMI1_TX1_P)
/CM5_HighSpeed/HDMI1_D2_N: J10.3 (D2-), Module1.148 (HDMI1_TX2_N)
/CM5_HighSpeed/HDMI1_D2_P: J10.1 (D2+), Module1.146 (HDMI1_TX2_P)
/CM5_HighSpeed/HDMI1_HOTPLUG: J10.19 (HPD/HEAC-), Module1.143 (HDMI1_HOTPLUG)
/CM5_HighSpeed/HDMI1_SCL: J10.15 (SCL), Module1.147 (HDMI1_SCL)
/CM5_HighSpeed/HDMI1_SDA: J10.16 (SDA), Module1.145 (HDMI1_SDA)
/CM5_HighSpeed/HDMI_5v: C13.1, J10.18 (+5V), J22.18 (+5V), U12.2 (OUT)
/CM5_HighSpeed/PCIE_CLK_N: Module1.112 (PCIe_CLK_N); also elsewhere on the board
/CM5_HighSpeed/PCIE_CLK_P: Module1.110 (PCIe_CLK_P); also elsewhere on the board
/CM5_HighSpeed/PCIE_PWR_EN: Module1.106 (PCIE_PWR_EN); also elsewhere on the board
/CM5_HighSpeed/PCIE_RX_N: Module1.118 (PCIe_RX_N); also elsewhere on the board
/CM5_HighSpeed/PCIE_RX_P: Module1.116 (PCIe_RX_P); also elsewhere on the board
/CM5_HighSpeed/PCIE_TX_N: Module1.124 (PCIe_TX_N); also elsewhere on the board
/CM5_HighSpeed/PCIE_TX_P: Module1.122 (PCIe_TX_P); also elsewhere on the board
/CM5_HighSpeed/PCIE_nCLKREQ: Module1.102 (PCIe_nCLKREQ); also elsewhere on the board
/CM5_HighSpeed/PCIE_nRST: Module1.109 (PCIe_nRST); also elsewhere on the board
/CM5_HighSpeed/PCIE_nWAKE: Module1.104 (PCIE_nWAKE); also elsewhere on the board
/CM5_HighSpeed/SCL0: J5.20; also elsewhere on the board
/CM5_HighSpeed/SCL1: J6.2, J16.20, R7.2
/CM5_HighSpeed/SDA0: J5.21; also elsewhere on the board
/CM5_HighSpeed/SDA1: J6.4, J16.21, R6.2
/CM5_HighSpeed/USB3-0-D_N: J12.A2 (D-), Module1.136 (USB3-0-D_N)
/CM5_HighSpeed/USB3-0-D_P: J12.A3 (D+), Module1.134 (USB3-0-D_P)
/CM5_HighSpeed/USB3-0-RX_N: J12.A6 (SSRX+), Module1.128 (USB3-0-RX_N)
/CM5_HighSpeed/USB3-0-RX_P: J12.A5 (SSRX-), Module1.130 (USB3-0-RX_P)
/CM5_HighSpeed/USB3-0-TX_N: J12.A9 (SSTX+), Module1.140 (USB3-0-TX_N)
/CM5_HighSpeed/USB3-0-TX_P: J12.A8 (SSTX-), Module1.142 (USB3-0-TX_P)
/CM5_HighSpeed/USB3-1-D_N: J12.B2 (D-), Module1.165 (USB3-1-D_N)
/CM5_HighSpeed/USB3-1-D_P: J12.B3 (D+), Module1.163 (USB3-1-D_P)
/CM5_HighSpeed/USB3-1-RX_N: J12.B6 (SSRX+), Module1.157 (USB3-1-RX_N)
/CM5_HighSpeed/USB3-1-RX_P: J12.B5 (SSRX-), Module1.159 (USB3-1-RX_P)
/CM5_HighSpeed/USB3-1-TX_N: J12.B9 (SSTX+), Module1.169 (USB3-1-TX_N)
/CM5_HighSpeed/USB3-1-TX_P: J12.B8 (SSTX-), Module1.171 (USB3-1-TX_P)
/CM5_HighSpeed/VBUS: C3.1, C7.1, C8.1, J12.A1 (VBUS), J12.B1 (VBUS), U6.6 (OUT)
/CM5_HighSpeed/VBUS_EN: Module1.111 (VBUS_EN), U6.3 (EN)
/USB2_N: Module1.103 (USB2_N); also elsewhere on the board
/USB2_P: Module1.105 (USB2_P); also elsewhere on the board
GND: C2.2, C3.2, C7.2, C8.2, C12.2, C13.2, J5.1, J5.4, J5.7, J5.10, J5.13, J5.16, J5.19, J10.2 (D2S), J10.5 (D1S), J10.8 (D0S), J10.11 (CKS), J10.17 (GND), J10.SH1 (SH), J10.SH2 (SH), J10.SH3 (SH), J10.SH4 (SH), J12.10 (SHIELD), J12.A4 (GND), J12.A7 (DRAIN), J12.B4 (GND), J12.B7 (DRAIN), J16.1, J16.4, J16.7, J16.10, J16.13, J16.16, J16.19, J22.2 (D2S), J22.5 (D1S), J22.8 (D0S), J22.11 (CKS), J22.17 (GND), J22.SH1 (SH), J22.SH2 (SH), J22.SH3 (SH), J22.SH4 (SH), Module1.107 (GND), Module1.108 (GND), Module1.113 (GND), Module1.114 (GND), Module1.119 (GND), Module1.120 (GND), Module1.125 (GND), Module1.126 (GND), Module1.131 (GND), Module1.132 (GND), Module1.137 (GND), Module1.138 (GND), Module1.144 (GND), Module1.150 (GND), Module1.155 (GND), Module1.156 (GND), Module1.161 (GND), Module1.162 (GND), Module1.167 (GND), Module1.168 (GND), Module1.173 (GND), Module1.174 (GND), Module1.179 (GND), Module1.180 (GND), Module1.185 (GND), Module1.186 (GND), Module1.191 (GND), Module1.192 (GND), Module1.197 (GND), Module1.198 (GND), R12.2, U6.2 (GND), U12.3 (GND); also elsewhere on the board
unnamed: J16.17, R8.2
unnamed: R12.1, U6.5 (ILIM)

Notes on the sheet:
USB 3 Pairs P/N swapped to help routing
Jumpers to be fitted if DPHY1 is used
Current Limit switch
DSI/CSI Connectors
Stacked USB connectors


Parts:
C4, C6, C14, C15, C16, C17: 10u; C_0805_2012Metric; Part Description 10uF 10% 10V Ceramic Capacitor X7R 0805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
C10, C19: 100n; C_0402_1005Metric; Part Description 0.1uF 10% 16V Ceramic Capacitor X7R 040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
C11: 4.7nF; C_0402_1005Metric; Part Description 4.7nF capacitor 0402
D3: LED Green; LED_0603_1608Metric; Part Description Green 572nm LED Indication - Discrete 2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
J4: Bus_M.2_Socket_M; M.2 M Key socket; Part Description M.2 M Key connector
L1: 2.2uH; L_Bourns_SRP5030CC; Part Description Inductor, SMT, 2520, 2u2, IRMS=7A, ISAT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
M1: M.2 Screw; Part Description M.2 Screw
M2, M3, M4, M5: M.2 Solder Nut; Part Description Solder nut for M.2 slot
R14: 100K 1%; R_0402_1005Metric; Part Description Resistor 100K M1005 1% 63mW
R15: 10K 1%; R_0402_1005Metric; Part Description Resistor 10K M1005 1% 63mW
R16: 2.2K 1%; R_0402_1005Metric; Part Description Resistor 2.2K M1005 1% 63mW
R17: 1k; R_0402_1005Metric; Part Description Resistor 1K M1005 1% 63mW
TP1: TestPoint; TestPoint_Pad_2.0x2.0mm; Part Description Test point; not fitted
U7: ASEK-32.768KHZ-L-R-T; Crystal_SMD_3225-4Pin_3.2x2.5mm; Part Description 32KHz Xtal oscilator
U8: AP3441SHE-7B; DFN-8-1EP_2x2mm_P0.5mm_EP1.05x1.75mm; Part Description 3A DC-DC converter

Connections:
/+5v: C4.1, C6.1, C10.1, U8.3 (VIN); also elsewhere on the board
/CM5_HighSpeed/PCIE_CLK_N: J4.53 (REFCLKn); also elsewhere on the board
/CM5_HighSpeed/PCIE_CLK_P: J4.55 (REFCLKp); also elsewhere on the board
/CM5_HighSpeed/PCIE_PWR_EN: R14.1, U8.7 (EN); also elsewhere on the board
/CM5_HighSpeed/PCIE_RX_N: J4.43 (PETp0); also elsewhere on the board
/CM5_HighSpeed/PCIE_RX_P: J4.41 (PETn0); also elsewhere on the board
/CM5_HighSpeed/PCIE_TX_N: J4.49 (PERp0); also elsewhere on the board
/CM5_HighSpeed/PCIE_TX_P: J4.47 (PERn0); also elsewhere on the board
/CM5_HighSpeed/PCIE_nCLKREQ: J4.52 (~CLKREQ); also elsewhere on the board
/CM5_HighSpeed/PCIE_nRST: J4.50 (~PERST); also elsewhere on the board
/CM5_HighSpeed/PCIE_nWAKE: J4.54 (~PEWAKE); also elsewhere on the board
/PCIe-M2/FB: C11.2, R15.2, R16.1, U8.1 (FB)
/PCIe-M2/M2_3v3: C11.1, C14.1, C15.1, C16.1, C17.1, C19.1, D3.2 (A), J4.2 (3.3V), J4.4 (3.3V), J4.12 (3.3V), J4.14 (3.3V), J4.16 (3.3V), J4.18 (3.3V), J4.70 (3.3V), J4.72 (3.3V), J4.74 (3.3V), L1.2, R15.1, U7.1 (EN), U7.4 (VDD)
GND: C4.2, C6.2, C10.2, C14.2, C15.2, C16.2, C17.2, C19.2, J4.1 (GND), J4.3 (GND), J4.9 (GND), J4.15 (GND), J4.21 (GND), J4.27 (GND), J4.33 (GND), J4.39 (GND), J4.45 (GND), J4.51 (GND), J4.57 (GND), J4.71 (GND), J4.73 (GND), J4.75 (GND), J4.M1 (GND2230), J4.M2 (GND2242), J4.M3 (GND2260), J4.M4 (GND2280), J4.S1, J4.S2, R14.2, R16.2, U7.2 (GND), U8.4 (PGND), U8.8 (SGND), U8.9 (PAD); also elsewhere on the board
unnamed: D3.1 (K), R17.1, TP1.1
unnamed: J4.10 (DAS/~DSS/~LED1), R17.2
unnamed: J4.68 (SUSCLK), U7.3 (Out)
unnamed: L1.1, U8.6 (LX)

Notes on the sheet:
Activity LED

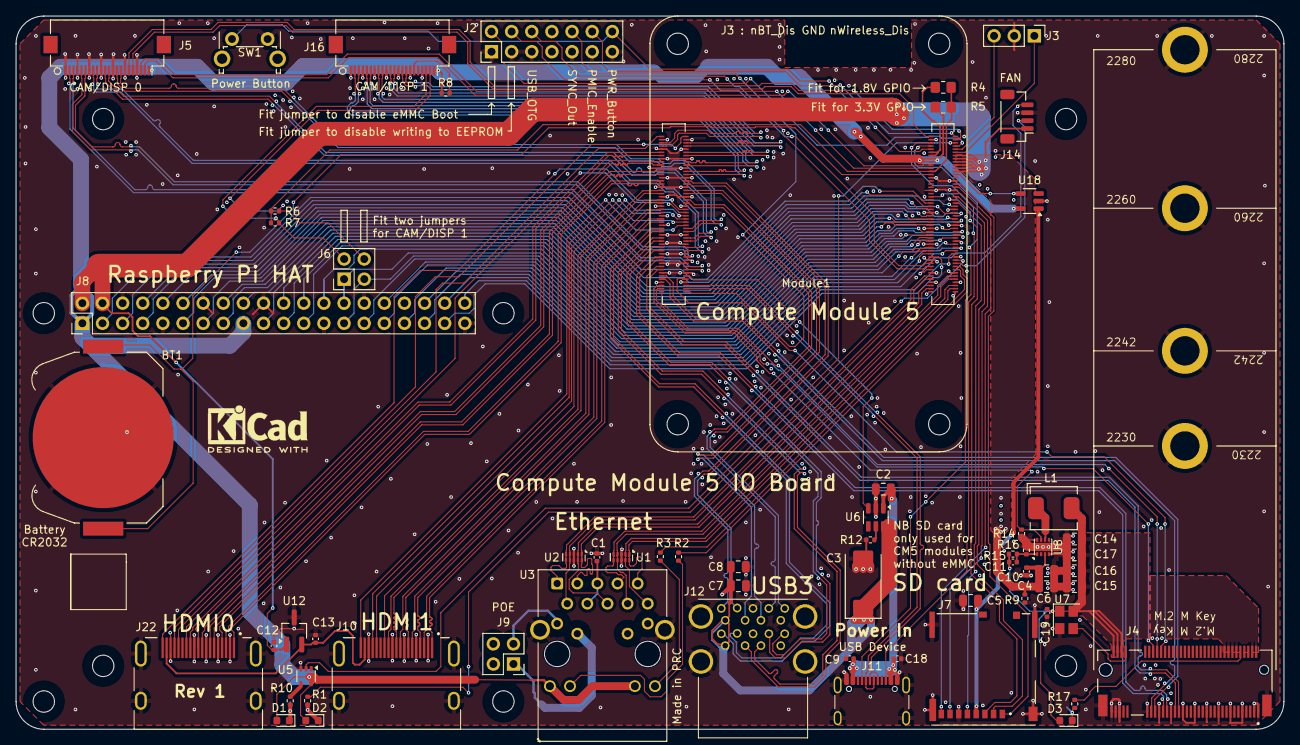
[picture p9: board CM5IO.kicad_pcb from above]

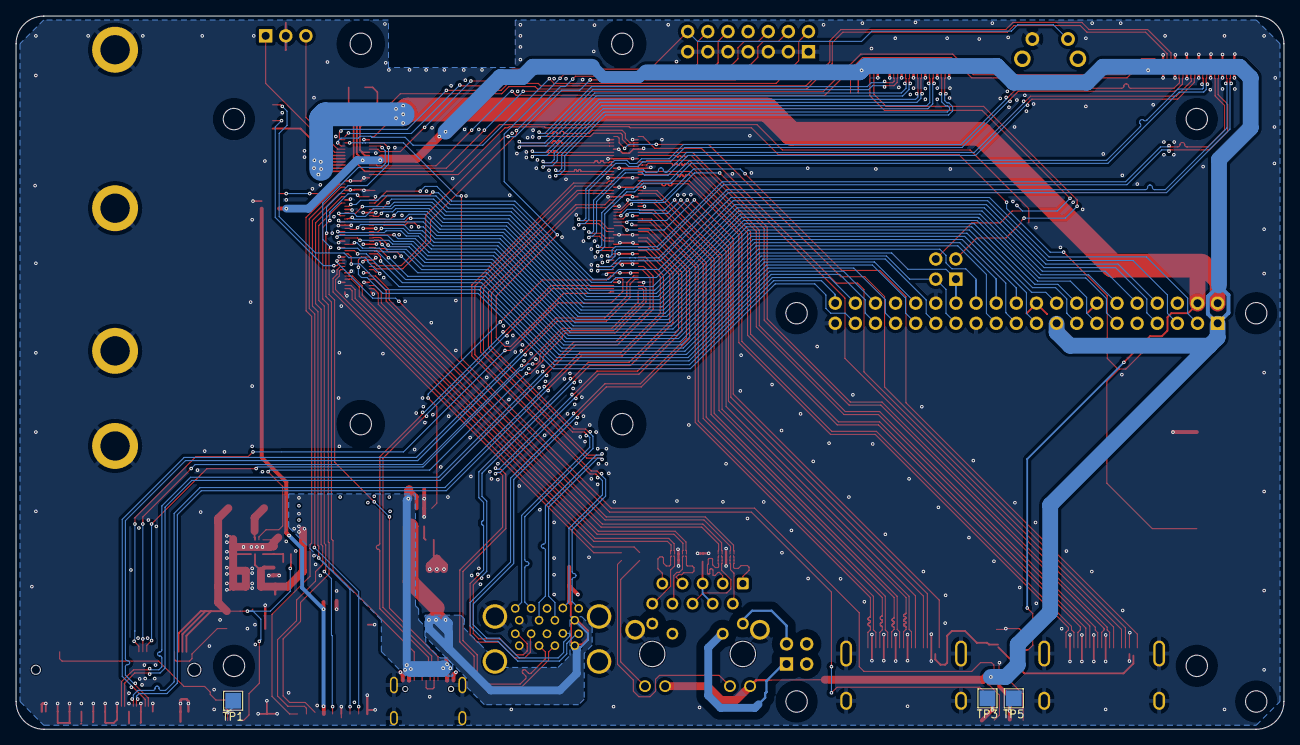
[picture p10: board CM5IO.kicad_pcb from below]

Board: 4 copper layers, 160.0 x 90.0 mm, 76 parts (3 on the bottom side), 161 nets.

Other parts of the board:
logo1: KiCad-Logo2_5mm_SilkScreen

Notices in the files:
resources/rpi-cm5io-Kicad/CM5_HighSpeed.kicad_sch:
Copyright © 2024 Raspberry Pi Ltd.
